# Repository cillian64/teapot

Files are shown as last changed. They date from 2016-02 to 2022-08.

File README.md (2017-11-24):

# TEApot
TEApot: Tiny Environment Analyser.  A
[ukhasnet](https://www.ukhas.net) node with various sensors.
ukhasnet node IDs `TEA0` through `TEAe`.

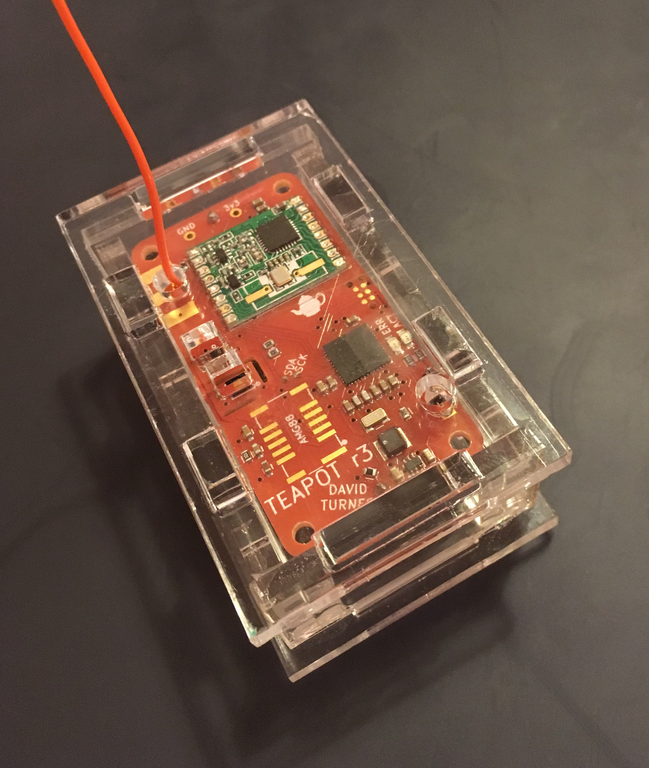
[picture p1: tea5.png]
Photo of TEA5


# Structure
* [board](board/) contains schematics and board layouts for KiCAD EDA 4
* [case](case/) contains plans for laser-cut cases for the nodes
* [firmware](firmware/) contains firmware for the various node flavours
* [software](software/) contains Python3 software for the USB gateway and
  GridEye receiver.

# Nodes
## Hardware
* Microcontroller: STM32F0 and STM32L0
* Power: AA or D alkaline cell with TLV61225 boost switcher
* Assorted sensors:
    * T: Temperature (HTU21d)
    * H: Humidity (HTU21d)
    * P: Pressure (MS5637)
    * S: Light (TEPT4400)
    * X: 8x8 thermopile array (AMG88 Grid-eye)

## Variants
* r2 was the first set manufactured.  Issues with I2C meant sensors did not
  work.  L0 variants are lower power than F0 but do not support USB.  L0
  variants include a RTC crystal.
* r3 was the second set manufactured, omitting USB but including support
  for the Grid-eye sensor and fixing I2C issues.  All boards include an RTC
  crystal.

Node | Board | Sensors | Status
---- | ----- | ------- | ------
TEA0 | r2 F0 |         | USB Gateway, working
TEA1 | r2 L0 |         | Repeater (needs firmware)
TEA2 | r2 L0 |         | Repeater (needs firmware)
TEA3 | r2 L0 |         | Repeater (needs antenna and firmware)
TEA4 | r2 L0 |         | Repeater (needs antenna and firmware)
TEA5 | r3    | THPS    | Working
TEA6 | r3    | THPS    | Working
TEA7 | r3    | THPS    | Working
TEA8 | r3    | THPS    | Working
TEA9 | r3    | THPS    | Working
TEAa | r3    | THPSX   | Grid-eye has checkerboard problem, otherwise ok
TEAb | r3    | THPSX   | Working
TEAc | r3    | THPSX   | Working
TEAd | r3    | THPSX   | Working
TEAe | r3    | THPSX   | Working

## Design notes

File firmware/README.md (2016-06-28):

# Firmware
* `r2` is the first firmware revision written in libopencm3 for the original
  STM32L052K6T6 teapot boards, marked r2.
* `r2_5` is the firmware for the original teapot boards (r2 PCB) with an
  STM32F042K6T7 retrofitted.
* `r3` is the firmware for the new r3 PCBs with an STM32F051C8U7, no USB, and
  the Panasonic Grid-eye AMG88 thermopile array.

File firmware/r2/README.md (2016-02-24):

# Toolchain
This firmware uses the
[gcc-arm-embedded](https://launchpad.net/gcc-arm-embedded) toolchain
recommended by libopencm3.  It can be installed on recent Ubuntu:

`sudo add-apt-repository ppa:team-gcc-arm-embedded/ppa`

`sudo apt-get update`

`sudo apt-get install gcc-arm-embedded`

# Submodules
Check out the correct version of libopencm3:

`git submodule update --init`

# Building, flashing, and debugging
Before doing anything else, build libopencm3:

`cd libopencm3`

`make`

`cd ..`

Then build and flash the firmware:

`make`

`make flash`

To debug:

`make debug`

# Sources
* `teapot.c` contains the start point, `main()`.
* `teapot_pins.h` contains pin assignments on the board, while `teapot_pins.h`
  contains the setup function which assigns pin modes.

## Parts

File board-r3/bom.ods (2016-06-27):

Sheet: BOM
Refs | Onecall part | Order q | Quantity/board | Quantity tot | Cost ea | Board cost | Order cost | N boards | Value | Footprint
D4 | 2290331 | 10 | 1 | 10 | £0.05 | £0.05 | £0.48 | 10 | GREEN | LED_0805
R101 | 9330798 | 10 | 1 | 10 | £0.00 | £0.00 | £0.01 | 10 | 20R | R_0603
C10 C101 C11 C13 C14 C15 C17 C7 | 432210 | 80 | 8 | 80 | £0.02 | £0.12 | £1.20 | 10 | 100n | C_0603
D5 | 2099242 | 10 | 1 | 10 | £0.05 | £0.05 | £0.53 | 10 | YELLOW | LED_0805
P1 | 1702629 | 5 | 1 | 5 | £0.75 | £0.75 | £3.73 | 10 | BATT | AA_holder
IC101 | 2469557 | 10 | 1 | 10 | £1.16 | £1.16 | £11.64 | 10 | STM32F0xxCxUx | QFN-48-EP-ST
C8 C9 | 1759055 | 20 | 2 | 20 | £0.01 | £0.02 | £0.19 | 10 | 15p | C_0603
R5 R6 | 9233385 | 20 | 2 | 20 | £0.01 | £0.01 | £0.10 | 10 | 1k | R_0603
L1 | 2470318 | 10 | 1 | 10 | £0.20 | £0.20 | £1.96 | 10 | 4u7 | Inductor_1212
C103 | 2211176 | 15 | 1 | 10 | £0.14 | £0.14 | £2.13 | 10 | 1.5uF | C_0603
C1 C104 C16 C3 C6 | 2494230 | 50 | 5 | 50 | £0.06 | £0.31 | £3.07 | 10 | 10u | C_0603
U2 | 2492362 | 10 | 1 | 10 | £0.65 | £0.65 | £6.49 | 10 | TLV61225 | SC-70
R1 R3 R4 R7 | 2447230 | 40 | 4 | 40 | £0.00 | £0.01 | £0.09 | 10 | 10k | R_0603
Q1 | SC12389 | 10 | 1 | 10 | £0.25 | £0.25 | £2.46 | 10 | TEPT4400 | LED-3MM
C102 C12 | 2496916 | 20 | 2 | 20 | £0.01 | £0.02 | £0.19 | 10 | 1u | C_0603
U4 | RF00489 | 10 | 1 | 10 | £6.29 | £6.29 | £62.90 | 10 | RFM69W | RFM69
Y1 | 2101347 | 10 | 1 | 10 | £0.34 | £0.34 | £3.43 | 10 | 32.768k | XTAL_1206
D1 D3 | 2368174 | 20 | 2 | 20 | £0.15 | £0.30 | £3.03 | 10 | TVS_small | R_0603
P1 | BT03723 | 5 | 1 | 5 | £0.72 | £0.72 | £3.60 | 5 | BATT | D_holder
OPTIONAL: HTU21D
U6 | 2393536 | 10 | 1 | 10 | £2.52 | £2.52 | £25.17 | 10 | HTU21D | HTU21D
OPTIONAL: MS5637
U7 | 2362663 | 10 | 1 | 10 | £1.51 | £1.51 | £15.09 | 10 | MS5637 | MS563702
OPTIONAL: AMG88
U101 | 2481446 | 5 | 1 | 5 | £23.87 | £23.87 | £119.35 | 5 | AMG88 | AMG88
Total cost per basic board |  |  |  |  |  | £10.66
Total cost per HTU21D/MS5637 board |  |  |  |  |  | £14.69
Total cost per AMG88 board |  |  |  |  |  | £34.53
Total cost per all-in board |  |  |  |  |  | £38.56
Total order cost |  |  |  |  |  | £263.23
Total order cost per board |  |  |  |  |  | £26.32

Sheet: QuickPaste
Onecall part | Order q | Value
2290331 | 10 | GREEN
9330798 | 10 | 20R
432210 | 80 | 100n
2099242 | 10 | YELLOW
1702629 | 5 | BATT
2469557 | 10 | STM32F0xxCxUx
1759055 | 20 | 15p
9233385 | 20 | 1k
2470318 | 10 | 4u7
2211176 | 15 | 1.5uF
2494230 | 50 | 10u
2492362 | 10 | TLV61225
2447230 | 40 | 10k
SC12389 | 10 | TEPT4400
2496916 | 20 | 1u
RF00489 | 10 | RFM69W
2101347 | 10 | 32.768k
2368174 | 20 | TVS_small
BT03723 | 5 | BATT
2393536 | 10 | HTU21D
2362663 | 10 | MS5637
2481446 | 5 | AMG88

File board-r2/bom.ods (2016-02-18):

Refs | Onecall part | Order q | Quantity/board | Quantity tot | Cost ea | Board cost | Order cost | Value | Footprint | Comment
D4 | 2290331 | 7 | 1 | 5 | £0.06 | £0.06 | £0.39 | GREEN | LED_0805
U1 | 1470478 | 1 | 1 | 5 | £0.17 | £0.17 | £0.17 | TPS79333DBVR | SOT-23-5 | Optional – USB
C10,C11,C13,C14,C15,C17,C2,C7 | 432210 | 50 | 8 | 40 | £0.01 | £0.04 | £0.26 | 100n | C_0603 | 1 Optional – USB, 1 optional – pressure
P1 | 1702629 | 4 | 1 | 5 | £0.75 | £0.75 | £2.98 | BATT | AA_holder
C8,C9 | 1759055 | 20 | 2 | 10 | £0.01 | £0.01 | £0.13 | 15p | C_0603
R2,R5,R6 | 9233385 | 20 | 3 | 15 | £0.00 | £0.01 | £0.07 | 1k | R_0603
U5 | 2488333 | 5 | 1 | 5 | £2.10 | £2.10 | £10.50 | STM32L052K6T6 | LQFP32_ST
U7 | 2362663 | 1 | 1 | 5 | £1.51 | £1.51 | £1.51 | MS5637 | MS563702 | Optional – Pressure
L1 | 2470318 | 5 | 1 | 5 | £0.18 | £0.18 | £0.91 | 4u7 | Inductor_1212
C1,C16,C3,C5,C6 | 2494230 | 30 | 5 | 25 | £0.04 | £0.21 | £1.24 | 10u | C_0603
D2 | 2099241 | 10 | 1 | 5 | £0.07 | £0.07 | £0.65 | RED | LED_0805
U2 | 2492362 | 4 | 1 | 5 | £0.63 | £0.63 | £2.53 | TLV61225 | SC-70
U6 | 2393536 | 5 | 1 | 5 | £2.52 | £2.52 | £12.59 | HTU21D | HTU21D
P2 | 1342651 | 1 | 1 | 5 | £2.87 | £2.87 | £2.87 | SMA | SMA-142-0701-801
J1 | 1568023 | 1 | 1 | 5 | £0.26 | £0.26 | £0.26 | MICROUSB | MICROUSB_MOLEX_47589-0001
R1,R3,R4,R7 | 2447230 | 30 | 4 | 20 | £0.00 | £0.02 | £0.12 | 10k | R_0603
Q1 | SC12389 | 5 | 1 | 5 | £0.25 | £0.25 | £1.23 | TEPT4400 | LED-3MM
C12 | 2496916 | 10 | 1 | 5 | £0.01 | £0.01 | £0.08 | 1u | C_0603
D5 | 2099242 | 10 | 1 | 5 | £0.06 | £0.06 | £0.64 | YELLOW | LED_0805
Y1 | 2101347 | 5 | 1 | 5 | £0.33 | £0.33 | £1.64 | 32.768k | XTAL_1206
D1,D3 | 2368174 | 10 | 2 | 10 | £0.15 | £0.30 | £1.52 | TVS_small | R_0603
U4 | RF00489 | 5 | 1 | 5 | £4.00 | £4.00 | £20.00 | RFM69HW-868S2 | RFM69W
TOTAL BOARD COST minus PCBs and tooling |  |  |  |  |  | £16.35
TOTAL ONECALL ORDER COST |  |  |  |  |  |  | £62.28
 |  |  |  | Total onecall per board |  |  | £12.46
 |  |  |  |  | £6.79

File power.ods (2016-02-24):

Component | Boost loss | stm32l052 | rfm69w | htu21d | ms5637 | tept4400 | total |  | All in uA referred to 3v3
Boost Quiescent | 20 | - | - | - | - | - | -
STM32 run | - | 3000 | - | - | - | - | -
STM32 sleep | - | 670 | - | - | - | - | -
STM32 LP run | - | 40 | - | - | - | - | -
STM32 LP sleep | - | 20 | - | - | - | - | -
STM32 Stop +RTC | - | 1 | - | - | - | - | -
RFM69W Sleep | - | - | 0.1 | - | - | - | -
RFM69W Idle +RC | - | - | 1.2 | - | - | - | -
RFM69W Standby +XTAL | - | - | 1250 | - | - | - | -
RFM69W RX | - | - | 16000 | - | - | - | -
RFM69W TX 0dBm | - | - | 20000 | - | - | - | -
RFM69W TX +13dBm | - | - | 45000 | - | - | - | -
HTU21D sleep | - | - | - | 0.02 | - | - | -
HTU21D measure | - | - | - | 450 | - | - | -
MS5637 standby | - | - | - | - | 0.01 | - | -
MS5637 measure | - | - | - | - | 20 | - | -
TEPT4400 dark | - | - | - | - | - | 5 | -
TEPT4400 hallway | - | - | - | - | - | 200 | -
TEPT4400 office | - | - | - | - | - | 800 | -
TEPT4400 overcast | - | - | - | - | - | 2000 | -
State |  |  |  |  |  |  |  | Time/ms
Sleep | 20.00 | 1.00 | 1.20 | 0.02 | 0.01 | 0.00 | 22.23 | 60000 | every minute
Measurement | 20.00 | 3000.00 | 0.10 | 450.00 | 20.00 | 800.00 | 4290.10 | 6
TX | 20.00 | 3000.00 | 45000.00 | 0.02 | 0.01 | 0.00 | 48020.03 | 33
RX (gateway) | 20.00 | 3000.00 | 16000.00 | 0.02 | 0.01 | 0.00 | 19020.03 | 0
TOTAL (time-average) | 20.00 | 2.95 | 25.93 | 0.06 | 0.01 | 0.08 | 49.04 | 60039
 |  |  |  |  |  |  | Ave I / uA: | 49.04
 |  |  |  |  |  |  | AA life | 22246.13 | hours
 |  |  |  |  |  |  | AA life | 926.92 | days
 |  |  |  |  |  |  | AA life | 2.54 | years

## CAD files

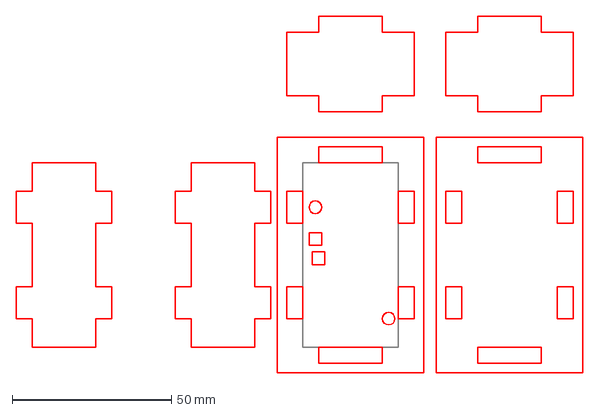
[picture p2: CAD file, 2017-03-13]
case/r3.dxf
178.0 x 112.0 mm

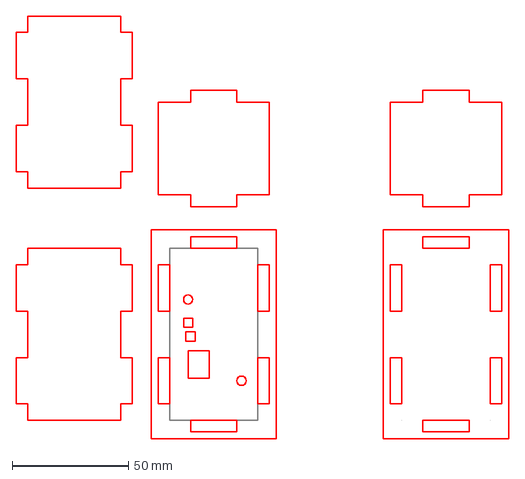
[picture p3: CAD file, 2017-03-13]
case/r3-grideye.dxf
212.0 x 182.0 mm

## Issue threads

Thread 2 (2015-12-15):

Check power consumption against boost regulator limit

cillian64, 2015-12-15:

cillian64, 2015-12-22:
stm32 at full whack plus transmit at +13dBm draws 48mA, which the booster can supply above 1V in.  Below that we might have issues.

Closed 2015-12-22.

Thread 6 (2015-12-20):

Add USB connector -- get fixed supervide schematic off adam

cillian64, 2015-12-20:

Closed 2015-12-21.

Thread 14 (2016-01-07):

mounting hole clearance

cillian64, 2016-01-07:

Closed 2016-01-07.

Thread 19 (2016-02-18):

Case holes failed

cillian64, 2016-02-18:
LED and antenna holes are too small and get merged closed, on quick print at least.

Closed 2016-02-19.

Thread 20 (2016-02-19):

Upper ledge for screw fixing is weird/unnecessary

cillian64, 2016-02-19:

Closed 2016-02-19.

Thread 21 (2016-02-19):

CS hole on lid, add insert to give clearance

cillian64, 2016-02-19:

Closed 2016-02-19.

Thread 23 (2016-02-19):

Walls are wibbly

cillian64, 2016-02-19:
Add ribs as appropriate

cillian64, 2017-11-24:
Laser-cut cases are no longer wibbly.

Closed 2017-11-24.

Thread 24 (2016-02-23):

Board is an excessively tight fit in case

cillian64, 2016-02-23:
Make everything bigger?
More headroom to include rfm69w?
Slot for TEPT4400
Or just rethink design from scratch?

cillian64, 2017-11-24:
Laser-cut cases are a perfect fit

Closed 2017-11-24.

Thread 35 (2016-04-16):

HTU21d footprint/pinout is wrong.

cillian64, 2016-04-16:

Closed 2016-06-17.

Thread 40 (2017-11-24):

Humidity sensor has some dropouts

cillian64, 2017-11-24:
It seems to depend on humidity level.  The latest firmware may fix this issue, I need to reflash all the nodes to find out.

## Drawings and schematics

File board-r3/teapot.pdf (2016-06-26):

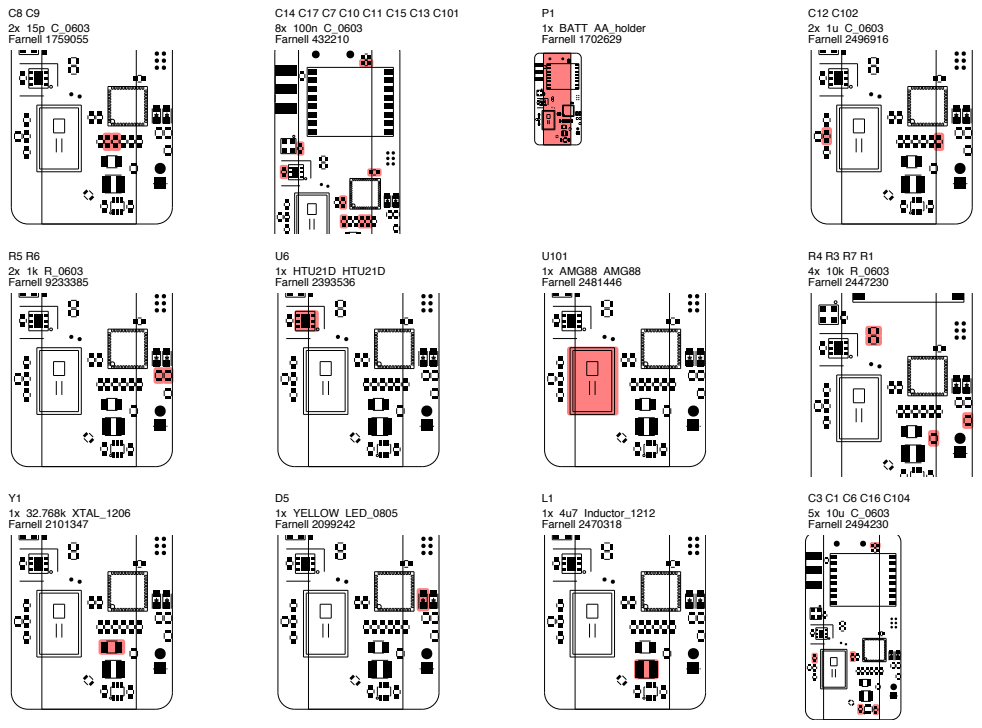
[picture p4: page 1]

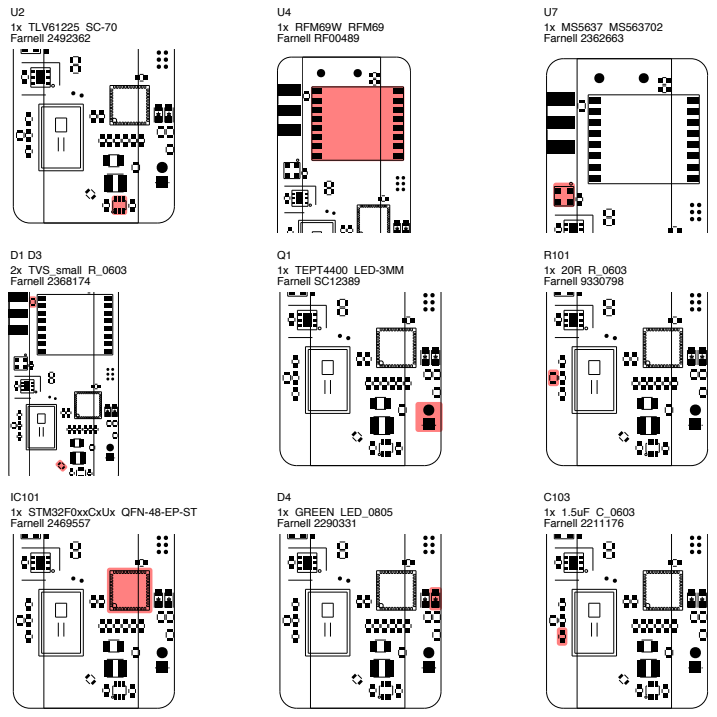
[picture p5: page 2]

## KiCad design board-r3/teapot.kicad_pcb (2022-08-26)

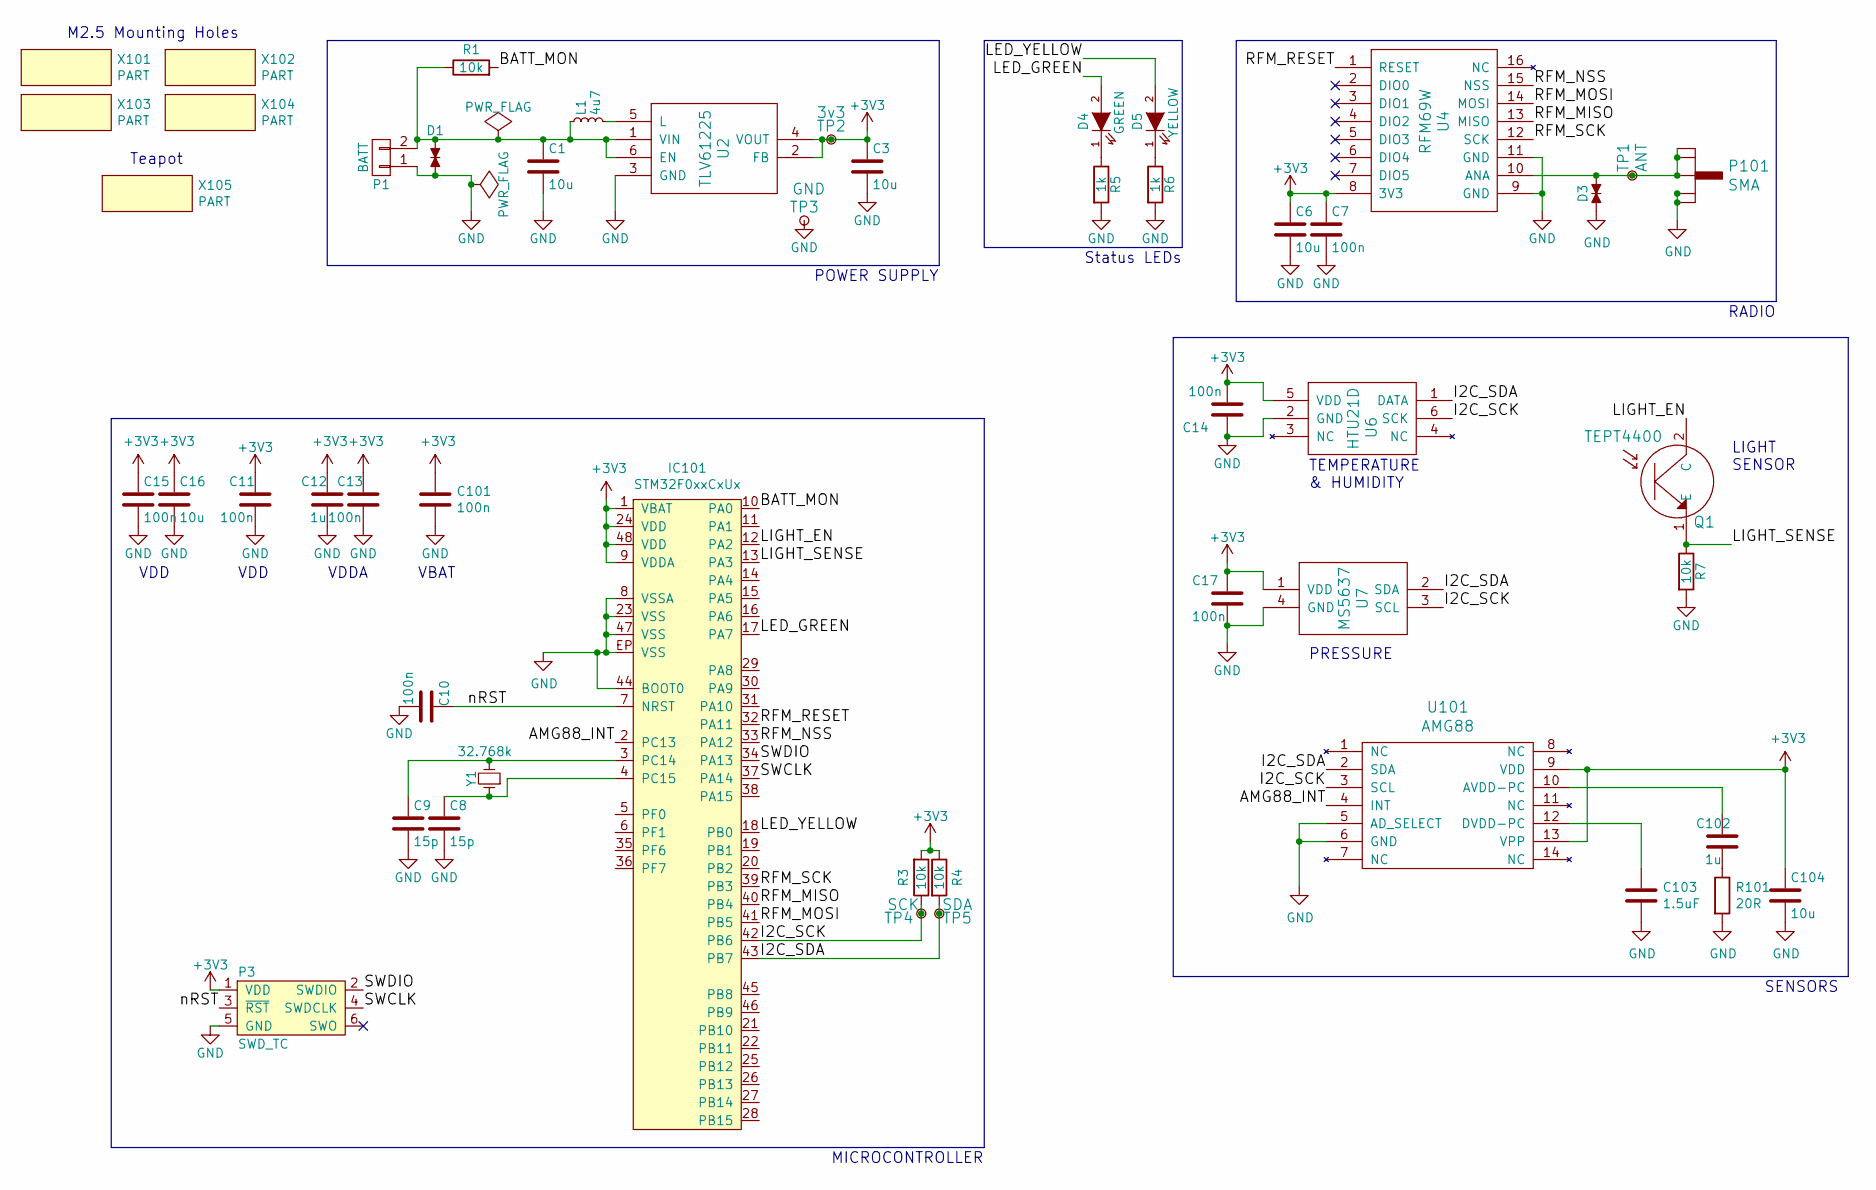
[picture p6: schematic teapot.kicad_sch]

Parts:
C1, C3, C6, C16, C104: 10u; C_0603; Farnell 2494230
C7, C10, C11, C13, C14, C15, C17, C101: 100n; C_0603; Farnell 432210
C8, C9: 15p; C_0603; Farnell 1759055
C12, C102: 1u; C_0603; Farnell 2496916
C103: 1.5uF; C_0603; Farnell 2211176
D1, D3: TVS_small; R_0603; Farnell 2368174
D4: GREEN; LED_0805; Farnell 2290331
D5: YELLOW; LED_0805; Farnell 2099242
IC101: STM32F0xxCxUx; QFN-48-EP-ST; Farnell 2469557
L1: 4u7; Inductor_1212; Farnell 2470318
P1: BATT; AA_holder; Farnell 1702629
P3: SWD_TC; TC2030-NL
P101: SMA; SMA-142-0701-801
Q1: TEPT4400; LED-3MM; Farnell SC12389
R1, R3, R4, R7: 10k; R_0603; Farnell 2447230
R5, R6: 1k; R_0603; Farnell 9233385
R101: 20R; R_0603; Farnell 9330798
TP1: ANT; Test_point
TP2: 3v3; Test_point
TP3: GND; Test_point
TP4: SCK; Test_point_mini
TP5: SDA; Test_point_mini
U2: TLV61225; SC-70; Farnell 2492362
U4: RFM69W; RFM69; Farnell RF00489
U6: HTU21D; Farnell 2393536
U7: MS5637; MS563702; Farnell 2362663
U101: AMG88; Farnell 2481446
X101, X102, X103, X104: PART; MountingHole_2.7mm_M2.5
X105: PART; teapot
Y1: 32.768k; XTAL_1206; Farnell 2101347

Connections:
+3V3: C3.1, C6.1, C7.1, C11.1, C12.1, C13.1, C14.2, C15.1, C16.1, C17.1, C101.1, C104.1, IC101.1 (VBAT), IC101.9 (VDDA), IC101.24 (VDD), IC101.48 (VDD), P3.1 (VDD), R3.2, R4.1, TP2.1, U2.2 (FB), U2.4 (VOUT), U4.8 (3V3), U6.5 (VDD), U7.1 (VDD), U101.9 (VDD), U101.13 (VPP)
/AMG88_INT: IC101.2 (PC13), U101.4 (INT)
/BATT_MON: IC101.10 (PA0), R1.2
/I2C_SCK: IC101.42 (PB6), R3.1, TP4.1, U6.6 (SCK), U7.3 (SCL), U101.3 (SCL)
/I2C_SDA: IC101.43 (PB7), R4.2, TP5.1, U6.1 (DATA), U7.2 (SDA), U101.2 (SDA)
/LED_GREEN: D4.2 (A), IC101.17 (PA7)
/LED_YELLOW: D5.2 (A), IC101.18 (PB0)
/LIGHT_EN: IC101.12 (PA2), Q1.2 (C)
/LIGHT_SENSE: IC101.13 (PA3), Q1.1 (E), R7.1
/RFM_MISO: IC101.40 (PB4), U4.13 (MISO)
/RFM_MOSI: IC101.41 (PB5), U4.14 (MOSI)
/RFM_NSS: IC101.33 (PA12), U4.15 (NSS)
/RFM_RESET: IC101.32 (PA11), U4.1 (RESET)
/RFM_SCK: IC101.39 (PB3), U4.12 (SCK)
/SWCLK: IC101.37 (PA14), P3.4 (SWDCLK)
/SWDIO: IC101.34 (PA13), P3.2 (SWDIO)
/nRST: C10.1, IC101.7 (NRST), P3.3 (~RST)
unnamed: C1.1, D1.1, L1.1, P1.2, R1.1, U2.1 (VIN), U2.6 (EN)
unnamed: C8.1, IC101.4 (PC15), Y1.1
unnamed: C9.1, IC101.3 (PC14), Y1.2
unnamed: C102.1, U101.10 (AVDD-PC)
unnamed: C102.2, R101.1
unnamed: C103.1, U101.12 (DVDD-PC)
unnamed: D4.1 (K), R5.1
unnamed: D5.1 (K), R6.1
unnamed: L1.2, U2.5 (L)

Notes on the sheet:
POWER SUPPLY
VBAT
SENSORS
PRESSURE
MICROCONTROLLER
M2.5 Mounting Holes
VDD
Teapot
LIGHT SENSOR
Status LEDs
TEMPERATURE & HUMIDITY
VDDA
RADIO

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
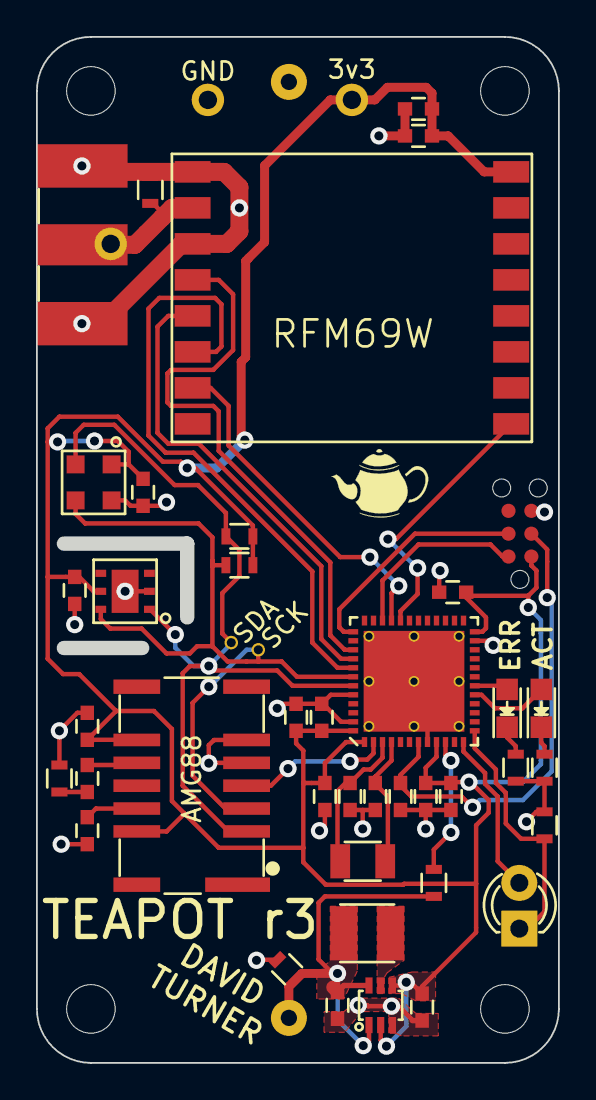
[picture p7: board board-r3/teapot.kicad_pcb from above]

Board: 2 copper layers, 29.0 x 57.0 mm, 51 parts (0 on the bottom side), 28 nets.

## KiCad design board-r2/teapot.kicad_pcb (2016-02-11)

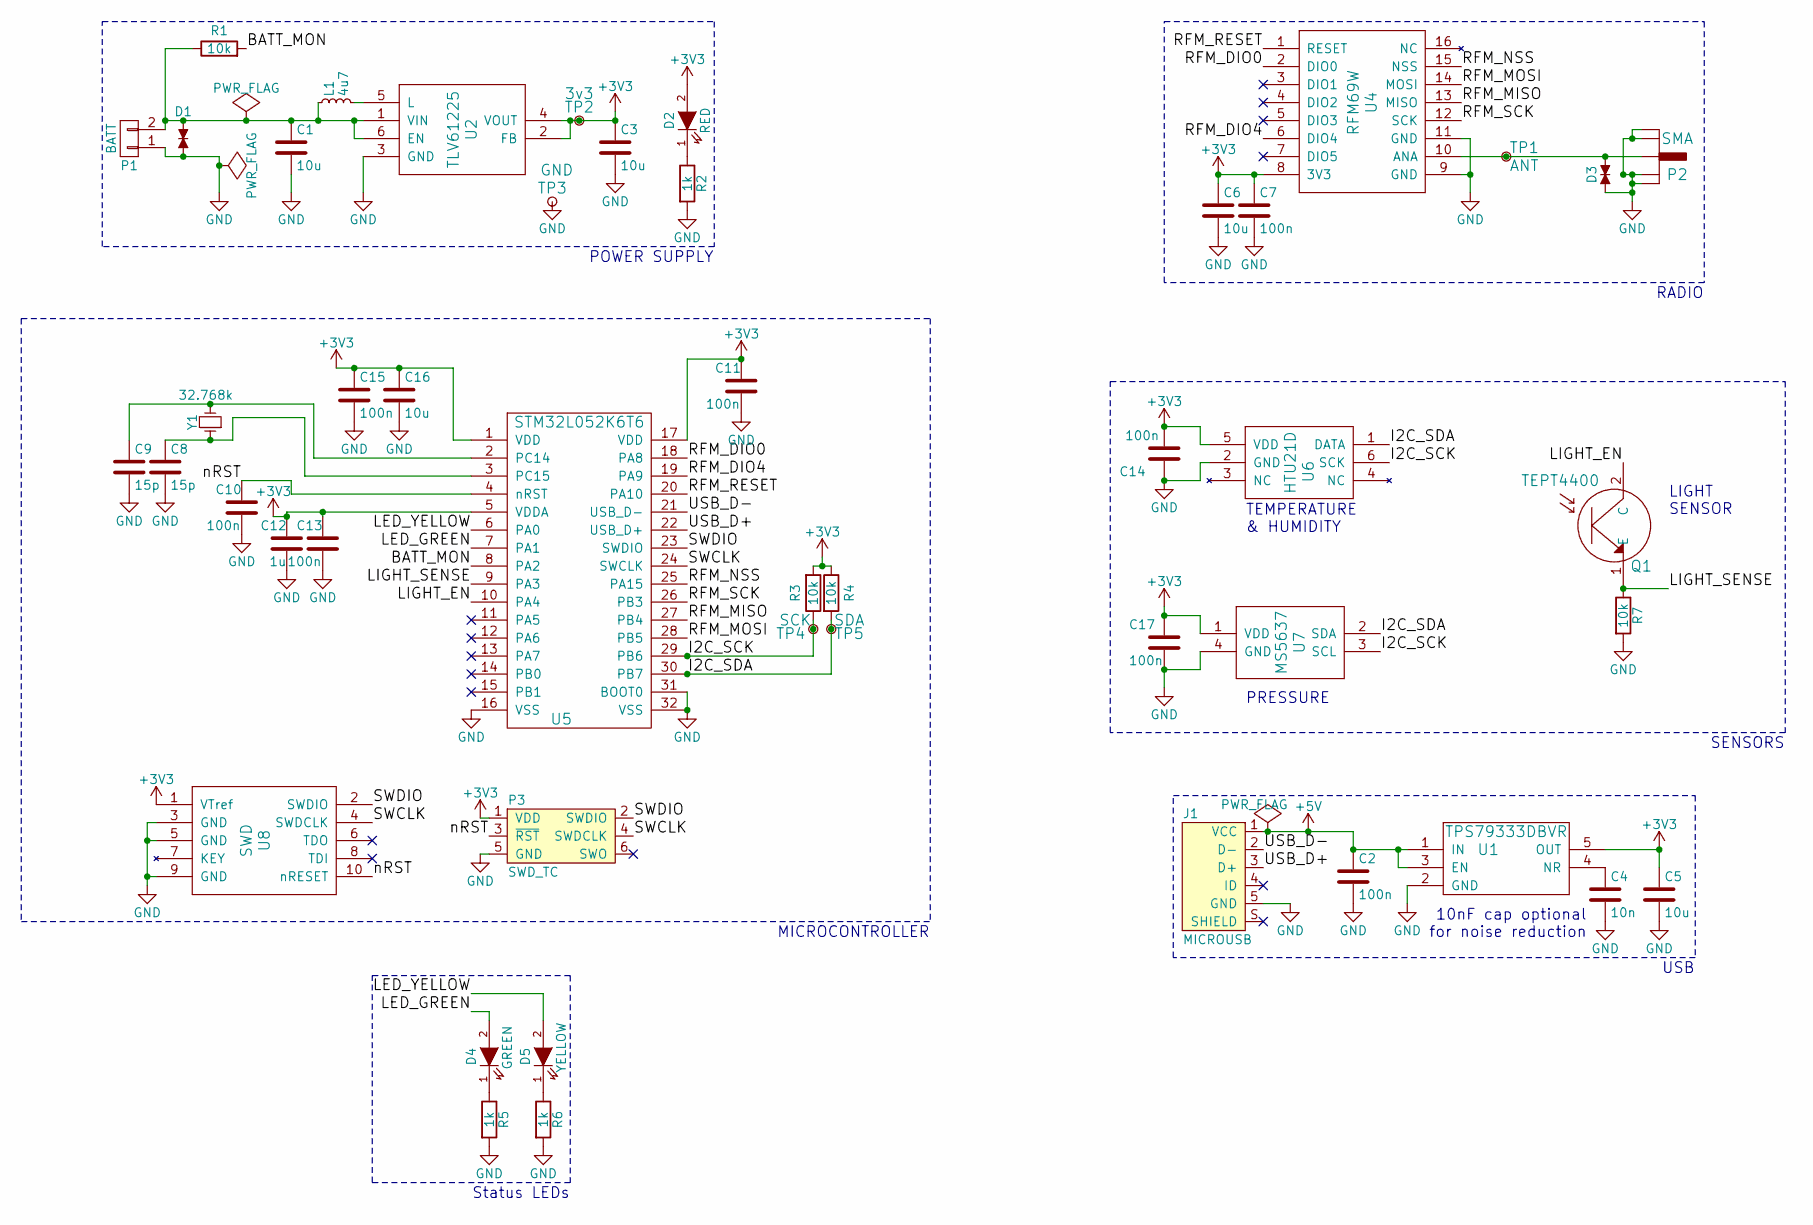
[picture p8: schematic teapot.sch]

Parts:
C1, C3, C5, C6, C16: 10u; C_0603; Farnell 2494230
C2, C7, C10, C11, C13, C14, C15, C17: 100n; C_0603; Farnell 432210
C4: 10n; C_0603
C8, C9: 15p; C_0603; Farnell 1759055
C12: 1u; C_0603; Farnell 2496916
D1, D3: TVS_small; R_0603; Farnell 2368174
D2: RED; LED_0805; Farnell 2099241
D4: GREEN; LED_0805; Farnell 2290331
D5: YELLOW; LED_0805; Farnell 2099242
J1: MICROUSB; MICROUSB_MOLEX_47589-0001; Farnell 1568023
L1: 4u7; Inductor_1212; Farnell 2470318
P1: BATT; AA_holder; Farnell 1702629
P2: SMA; SMA-142-0701-801; Farnell 1342651
P3: SWD_TC; TC2030-NL
Q1: TEPT4400; LED-3MM; Farnell SC12389
R1, R3, R4, R7: 10k; R_0603; Farnell 2447230
R2, R5, R6: 1k; R_0603; Farnell 9233385
TP1: ANT; Test_point
TP2: 3v3; Test_point
TP3: GND; Test_point
TP4: SCK; Test_point_mini
TP5: SDA; Test_point_mini
U1: TPS79333DBVR; SOT-23-5; Farnell 1470478
U2: TLV61225; SC-70; Farnell 2492362
U4: RFM69W; RFM69
U5: STM32L052K6T6; LQFP32_ST; Farnell 2488333
U6: HTU21D; Farnell 2393536
U7: MS5637; MS563702; Farnell 2362663
U8: SWD
Y1: 32.768k; XTAL_1206; Farnell 2101347

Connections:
+3V3: C3.1, C5.1, C6.1, C7.1, C11.1, C12.1, C13.1, C14.2, C15.1, C16.1, C17.1, D2.2 (A), P3.1 (VDD), R3.2, R4.1, TP2.1, U1.5 (OUT), U2.2 (FB), U2.4 (VOUT), U4.8 (3V3), U5.1 (VDD), U5.5 (VDDA), U5.17 (VDD), U6.5 (VDD), U7.1 (VDD), U8.1 (VTref)
+5V: C2.1, J1.1 (VCC), U1.1 (IN), U1.3 (EN)
/BATT_MON: R1.2, U5.8 (PA2)
/I2C_SCK: R3.1, TP4.1, U5.29 (PB6), U6.6 (SCK), U7.3 (SCL)
/I2C_SDA: R4.2, TP5.1, U5.30 (PB7), U6.1 (DATA), U7.2 (SDA)
/LED_GREEN: D4.2 (A), U5.7 (PA1)
/LED_YELLOW: D5.2 (A), U5.6 (PA0)
/LIGHT_EN: Q1.2 (C), U5.10 (PA4)
/LIGHT_SENSE: Q1.1 (E), R7.1, U5.9 (PA3)
/RFM_DIO0: U4.2 (DIO0), U5.18 (PA8)
/RFM_DIO4: U4.6 (DIO4), U5.19 (PA9)
/RFM_MISO: U4.13 (MISO), U5.27 (PB4)
/RFM_MOSI: U4.14 (MOSI), U5.28 (PB5)
/RFM_NSS: U4.15 (NSS), U5.25 (PA15)
/RFM_RESET: U4.1 (RESET), U5.20 (PA10)
/RFM_SCK: U4.12 (SCK), U5.26 (PB3)
/SWCLK: P3.4 (SWDCLK), U5.24 (SWCLK), U8.4 (SWDCLK)
/SWDIO: P3.2 (SWDIO), U5.23 (SWDIO), U8.2 (SWDIO)
/USB_D+: J1.3 (D+), U5.22 (USB_D+)
/USB_D-: J1.2 (D-), U5.21 (USB_D-)
/nRST: C10.1, P3.3 (~RST), U5.4 (nRST), U8.10 (nRESET)
GND: C1.2, C2.2, C3.2, C4.2, C5.2, C6.2, C7.2, C8.2, C9.2, C10.2, C11.2, C12.2, C13.2, C14.1, C15.2, C16.2, C17.2, D1.2, D3.1, J1.5 (GND), P1.1, P2.2 (GND), P2.3 (GND), P2.4 (GND), P2.5 (GND), P3.5 (GND), R2.2, R5.2, R6.2, R7.2, TP3.1, U1.2 (GND), U2.3 (GND), U4.9 (GND), U4.11 (GND), U5.16 (VSS), U5.31 (BOOT0), U5.32 (VSS), U6.2 (GND), U7.4 (GND), U8.3 (GND), U8.5 (GND), U8.9 (GND)
unnamed: C1.1, D1.1, L1.1, P1.2, R1.1, U2.1 (VIN), U2.6 (EN)
unnamed: C4.1, U1.4 (NR)
unnamed: C8.1, U5.3 (PC15), Y1.1
unnamed: C9.1, U5.2 (PC14), Y1.2
unnamed: D2.1 (K), R2.1
unnamed: D3.2, P2.1 (RF), TP1.1, U4.10 (ANA)
unnamed: D4.1 (K), R5.1
unnamed: D5.1 (K), R6.1
unnamed: L1.2, U2.5 (L)

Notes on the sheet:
PRESSURE
TEMPERATURE & HUMIDITY
POWER SUPPLY
LIGHT SENSOR
RADIO
MICROCONTROLLER
USB
10nF cap optional for noise reduction
Status LEDs
SENSORS

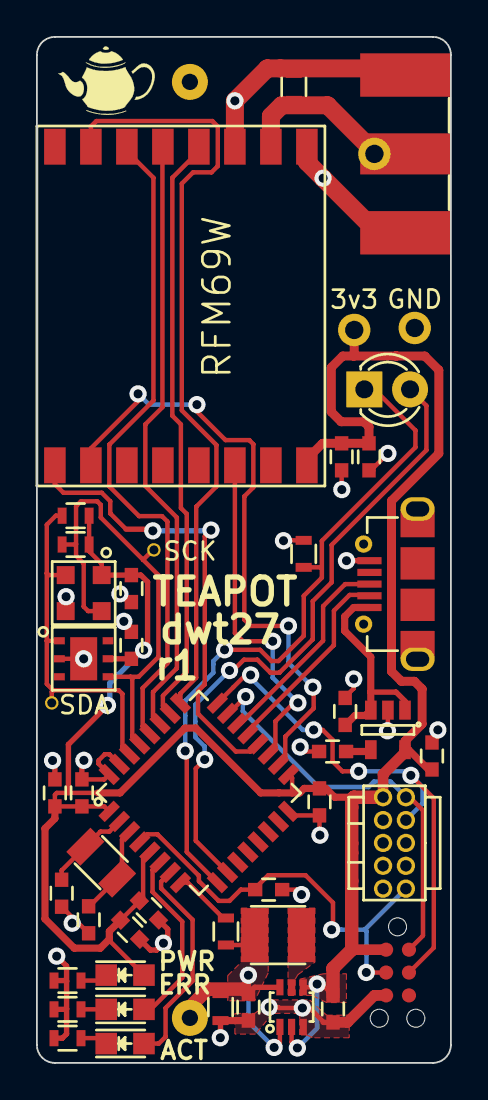
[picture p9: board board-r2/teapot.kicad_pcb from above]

Board: 2 copper layers, 23.0 x 57.0 mm, 48 parts (0 on the bottom side), 31 nets.

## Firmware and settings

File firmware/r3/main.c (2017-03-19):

#include <string.h>

#include "ch.h"
#include "hal.h"
#include "ch_test.h"

#include "analog.h"
#include "rfm69.h"
#include "ukhasnet.h"
#include "grid-eye.h"
#include "sensors.h"
#include "base64.h"
#include "flash.h"
#include "lowpower.h"

#ifdef SEMIHOSTING
#include <stdio.h>
#endif

static const I2CConfig i2cconfig = {
//    0xffff,
    1<<31 | 1<<30 | 1<<29 | 1<<28, // TIMINGR
    0,      // CR1
    0,      // CR2
};

#ifdef SEMIHOSTING
void initialise_monitor_handles(void);

/* Puts with no newline */
void puts_non(char *str);
void puts_non(char *str)
{
    for(uint32_t i=0; i<strlen(str); i++)
        putchar(str[i]);
}
#endif

int main(void)
{
    halInit();
    chSysInit();

    flash_config_t *config = chHeapAlloc(NULL, sizeof(flash_config_t));
    // Uncomment below to write config to flash memory.
    // strcpy(config->nodeid, "TEA8");
    // config->ttl = 3;
    // config->interval = 60;
    // config->has_battery = true;
    // config->has_temperature = true;
    // config->has_humidity = true;
    // config->has_pressure = true;
    // config->has_light = false;
    // config->has_grideye = false;
    // flash_write_config(config);
    flash_read_config(config);

    char seq;
    if(lowpower_woken_from_standby())
        seq = lowpower_get_sequence();
    else
        seq = 'a';

    analog_init();
    ukhasnet_radio_init();

    // On first boot wait for things to warm up to avoid weird i2c issues
    if(seq == 'a')
        chThdSleepMilliseconds(1000);

    palClearLine(LINE_LED_YELLOW);
    palClearLine(LINE_LED_GREEN);

#ifdef SEMIHOSTING
    initialise_monitor_handles();
    setbuf(stdout, NULL);
    puts("Hello, world.");
#endif

    spiStop(&SPID1);
    i2cStart(&I2CD1, &i2cconfig);
    pressure_init();
    i2cStop(&I2CD1);

    // Buffers
    uint8_t *packetbuf = chHeapAlloc(NULL, 64*sizeof(uint8_t));

    // GRIDEYE stuff.  Allocate whether or not we actually have a grideye
    uint16_t *pixels = chHeapAlloc(NULL, 64*sizeof(uint16_t));
    uint8_t *packed_pixels = chHeapAlloc(NULL, 36*sizeof(uint8_t));
    char *b64_pixels = chHeapAlloc(NULL, 49*sizeof(char));
    uint16_t grid_average;

    uint8_t packet_len;
    uint32_t pressure;
    uint8_t battery;
    uint16_t light;
    uint16_t temperature;
    uint8_t humidity;

    while(true)
    {
        // Begin activity
        palSetLine(LINE_LED_GREEN);

        // Read analog sensors.
        analog_read(&battery, &light);
        // Read I2C sensors. Swap from SPI to I2C
        spiStop(&SPID1);
        i2cStart(&I2CD1, &i2cconfig);
        temperature = convert_temperature(get_temperature());
        humidity = convert_humidity(get_humidity());
        pressure = get_pressure();
        if(config->has_grideye)
            grideye_get(pixels);
        i2cStop(&I2CD1);
        ukhasnet_radio_init();

       // Send sensor packet:
       packet_len = makepacket(packetbuf, 64, &seq, config->nodeid,
                               config->ttl,
                               config->has_battery, battery,
                               config->has_temperature, temperature,
                               config->has_humidity, humidity,
                               config->has_pressure, pressure,
                               config->has_light, light,
                               "");
       rfm69_transmit(packetbuf, packet_len);

        // For Grid-eye send another packet with pixels:
        if(config->has_grideye)
        {
            chThdSleepMilliseconds(100);
            grid_average = grideye_pack(pixels, packed_pixels);
            packed_pixels[32] = grid_average >> 8;
            packed_pixels[33] = grid_average & 0xff;
            packed_pixels[34] = pixels[32] >> 8;
            packed_pixels[35] = pixels[32] & 0xff;
            b64encode(packed_pixels, 36, b64_pixels);
            b64_pixels[48] = '\0';

            packet_len = makepacket(packetbuf, 64, &seq,
                                    config->nodeid,
                                    0, // Disable grideye repeating
                                    false, 0, false, 0, false, 0,
                                    false, 0, false, 0,
                                    b64_pixels);
            rfm69_transmit(packetbuf, packet_len);
        }

        // End activity and clean up for standby mode
        palClearLine(LINE_LED_GREEN);
        rfm69_setmode(RFM69_OPMODE_SLEEP);
        i2cStop(&I2CD1);
        spiStop(&SPID1);
        adcStop(&ADCD1);

        lowpower_set_sequence(seq);
        lowpower_set_wakeup_timer(config->interval);
        lowpower_do_standby();
    }
}

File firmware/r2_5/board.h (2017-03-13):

/*
    ChibiOS - Copyright (C) 2006..2016 Giovanni Di Sirio

    Licensed under the Apache License, Version 2.0 (the "License");
    you may not use this file except in compliance with the License.
    You may obtain a copy of the License at

        http://www.apache.org/licenses/LICENSE-2.0

    Unless required by applicable law or agreed to in writing, software
    distributed under the License is distributed on an "AS IS" BASIS,
    WITHOUT WARRANTIES OR CONDITIONS OF ANY KIND, either express or implied.
    See the License for the specific language governing permissions and
    limitations under the License.
*/

#ifndef BOARD_H
#define BOARD_H

/*
 * Board identifier.
 */
#define BOARD_NAME                  "Teapot r2.5"

/*
 * Board oscillators-related settings.
 * NOTE: HSE not fitted.
 * NOTE: LSE fitted but not connected, because pins not available
 */
#if !defined(STM32_LSECLK)
#define STM32_LSECLK                0U
#endif

#define STM32_LSEDRV                (3U << 3U)

#if !defined(STM32_HSECLK)
#define STM32_HSECLK                0U
#endif

/*
 * MCU type as defined in the ST header.
 */
#define STM32F042x6

/*
 * IO pins assignments.
 */
#define GPIOA_LED_YELLOW            0U
#define GPIOA_LED_GREEN             1U
#define GPIOA_BATT_MON              2U
#define GPIOA_LIGHT_SENSE           3U
#define GPIOA_LIGHT_EN              4U
#define GPIOA_PIN5                  5U
#define GPIOA_PIN6                  6U
#define GPIOA_PIN7                  7U
#define GPIOA_RFM_DIO0              8U
#define GPIOA_RFM_DIO4              9U
#define GPIOA_RFM_RESET             10U
#define GPIOA_USB_DM                11U
#define GPIOA_USB_DP                12U
#define GPIOA_SWDIO                 13U
#define GPIOA_SWCLK                 14U
#define GPIOA_RFM_NSS               15U

#define GPIOB_PIN0                  0U
#define GPIOB_PIN1                  1U
#define GPIOB_PIN2                  2U
#define GPIOB_RFM_SCK               3U
#define GPIOB_RFM_MISO              4U
#define GPIOB_RFM_MOSI              5U
#define GPIOB_I2C_SCK               6U
#define GPIOB_I2C_SDA               7U
#define GPIOB_PIN8                  8U
#define GPIOB_PIN9                  9U
#define GPIOB_PIN10                 10U
#define GPIOB_PIN11                 11U
#define GPIOB_PIN12                 12U
#define GPIOB_PIN13                 13U
#define GPIOB_PIN14                 14U
#define GPIOB_PIN15                 15U

#define GPIOC_PIN0                  0U
#define GPIOC_PIN1                  1U
#define GPIOC_PIN2                  2U
#define GPIOC_PIN3                  3U
#define GPIOC_PIN4                  4U
#define GPIOC_PIN5                  5U
#define GPIOC_PIN6                  6U
#define GPIOC_PIN7                  7U
#define GPIOC_PIN8                  8U
#define GPIOC_PIN9                  9U
#define GPIOC_PIN10                 10U
#define GPIOC_PIN11                 11U
#define GPIOC_PIN12                 12U
#define GPIOC_PIN13                 13U
#define GPIOC_PIN14                 14U
#define GPIOC_PIN15                 15U

#define GPIOD_PIN0                  0U
#define GPIOD_PIN1                  1U
#define GPIOD_PIN2                  2U
#define GPIOD_PIN3                  3U
#define GPIOD_PIN4                  4U
#define GPIOD_PIN5                  5U
#define GPIOD_PIN6                  6U
#define GPIOD_PIN7                  7U
#define GPIOD_PIN8                  8U
#define GPIOD_PIN9                  9U
#define GPIOD_PIN10                 10U
#define GPIOD_PIN11                 11U
#define GPIOD_PIN12                 12U
#define GPIOD_PIN13                 13U
#define GPIOD_PIN14                 14U
#define GPIOD_PIN15                 15U

#define GPIOE_PIN0                  0U
#define GPIOE_PIN1                  1U
#define GPIOE_PIN2                  2U
#define GPIOE_PIN3                  3U
#define GPIOE_PIN4                  4U
#define GPIOE_PIN5                  5U
#define GPIOE_PIN6                  6U
#define GPIOE_PIN7                  7U
#define GPIOE_PIN8                  8U
#define GPIOE_PIN9                  9U
#define GPIOE_PIN10                 10U
#define GPIOE_PIN11                 11U
#define GPIOE_PIN12                 12U
#define GPIOE_PIN13                 13U
#define GPIOE_PIN14                 14U
#define GPIOE_PIN15                 15U

#define GPIOF_PIN0                  0U
#define GPIOF_PIN1                  1U
#define GPIOF_PIN2                  2U
#define GPIOF_PIN3                  3U
#define GPIOF_PIN4                  4U
#define GPIOF_PIN5                  5U
#define GPIOF_PIN6                  6U
#define GPIOF_PIN7                  7U
#define GPIOF_PIN8                  8U
#define GPIOF_PIN9                  9U
#define GPIOF_PIN10                 10U
#define GPIOF_PIN11                 11U
#define GPIOF_PIN12                 12U
#define GPIOF_PIN13                 13U
#define GPIOF_PIN14                 14U
#define GPIOF_PIN15                 15U
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

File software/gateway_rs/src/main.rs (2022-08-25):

use std::io::BufRead;
use std::io::BufReader;
use std::time::Duration;

mod ukhn_to_influx;

/// Gateway name
const ORIGIN: &str = "TEA0";

/// Open a serial port at the specified path.  Keeps trying (and blocks) until
/// we can successfully open one.
///
/// # Arguments
///
/// * `path` - OS-dependent path to the serial port to open
///
/// # Returns
///
/// * Some sort of serial port (which type depends on the OS).
fn open_serial_port(path: &str) -> Box<dyn serialport::SerialPort> {
    let timeout = Duration::new(1, 0); // one second
    loop {
        let maybe_port = serialport::new(path, 115_200).timeout(timeout).open();
        if let Ok(port) = maybe_port {
            return port;
        }
    }
}

/// Try to upload a packet to InfluxDB.  No action is taken if the upload
/// fails.
///
/// # Arguments
///
/// * `packet` - Trimmed string received from the gateway hardware
fn upload_to_influx(line: &str) {
    let url = "http://localhost:8086/write?db=ukhasnet";

    eprintln!("line: {}", line);

    if let Err(e) = ureq::post(url)
        .set("Content-Type", "text/plain; charset=utf-8")
        .set("Accept", "application/json")
        .send_string(line)
    {
        // If upload fails then print a warning and discard the packet.  We
        // could buffer packets which don't upload.
        match e {
            ureq::Error::Status(_code, response) => {
                eprintln!("Influx POST returned response {:?}", response);
                eprintln!("Influx response body {}", response.into_string().unwrap());
            }
            ureq::Error::Transport(t) => {
                eprintln!("Transport error posting to influx: {:?}", t);
            }
        }
    }
}

fn main() {
    let path = "/dev/ttyACM0";
    println!("Opening serial port");
    let port = open_serial_port(path);
    println!("Making new bufreader");
    let b = BufReader::new(port);
    println!("Waiting for lines....");

    for line in b.lines().into_iter().flatten() {
        // Trim off whitespace
        let line = line.trim();

        println!("Received: {}", line);

        // Ignore any malformed packets
        match ukhasnet_parser::parse(&line.to_owned()) {
            Ok(mut packet) => {
                // Add this gateway to the packet's path
                packet.path.push(ORIGIN.to_owned());

                // Ignore any packets which can't be made into an influx string
                if let Ok(influx_str) = ukhn_to_influx::packet_to_influx(line, &packet) {
                    upload_to_influx(&influx_str);
                }
            },
            Err(e) => eprintln!("Parse failed: '{}' {}", line, e),
        }
    }
}

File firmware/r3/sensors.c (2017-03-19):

#include <stdint.h>
#include <stdbool.h>

#include "ch.h"
#include "hal.h"

#include "sensors.h"
#include "util.h"

const uint8_t ms5637_address = 0b01110110;
uint16_t ms5637_prom[7];
const uint8_t htu21d_address = 0x40;

/* Convert raw temperature from HTU21D to signed integer 0.1C */
int32_t convert_temperature(uint16_t raw)
{
    int64_t temp = raw;
    temp *= 175720;
    temp /= (1<<16);
    temp -= 46850;
    temp /= 100;
    return temp;
}

/* Convert raw humidity from HTU21D to unsigned integer RH percent */
uint8_t convert_humidity(uint16_t raw)
{
    uint32_t hum = raw;
    hum *= 125;
    hum /= (1<<16);
    hum -= 6;
    return hum;
}

/* Get temperature from HTU21D */
uint16_t get_temperature(void)
{
    uint8_t tx_buf[1];
    uint8_t rx_buf[3] = {0, 0, 0};
    msg_t result;

    tx_buf[0] = 0xe3; /* temperature, hold master */

    /* Transmit command to begin temperature measurement */
    result = i2cMasterTransmitTimeout(&I2CD1,
                                      htu21d_address,   // address
                                      tx_buf, 1,        // tx buffer and length
                                      rx_buf, 0,        // rx buffer and length
                                      TIME_INFINITE);   // No timeout
    if(result != MSG_OK)
    {
        volatile uint8_t error = i2cGetErrors(&I2CD1);
        panic("Temperature cmd return != MSG_OK");
    }

    /* Now try to read back -- slave will hold until ready */
    result = i2cMasterReceiveTimeout(&I2CD1,
                                     htu21d_address,    // address
                                     rx_buf, 3,         // rx buffer and length
                                     TIME_INFINITE);
    if(result != MSG_OK)
    {
        volatile uint8_t error = i2cGetErrors(&I2CD1);
        panic("Temperature read return != MSG_OK");
    }

    // Sometimes MSbit of MSB sometimes gets improbably set
    rx_buf[0] &= 0x7f;

//    if(rx_buf[1] & 0x02)
//        panic("Temperature result is of type humidity!");

    /* Retrieve 14-bit measurement, ignoring 2 LSBits */
    return ((uint16_t)rx_buf[0] << 8) | (rx_buf[1] & 0b11111100);
}

/* Get humidity from HTU21D */
uint16_t get_humidity(void)
{
    uint8_t tx_buf[1];
    uint8_t rx_buf[3];
    msg_t result;

    tx_buf[0] = 0xe5; /* humidity, hold master */

    /* Transmit command to begin humidity measurement */
    result = i2cMasterTransmitTimeout(&I2CD1,
                                      htu21d_address,   // address
                                      tx_buf, 1,        // tx buffer and length
                                      rx_buf, 0,        // rx buffer and length
                                      TIME_INFINITE);   // No timeout
    if(result != MSG_OK)
    {
        volatile uint8_t error = i2cGetErrors(&I2CD1);
        panic("Humidity cmd return != MSG_OK");
    }

    /* Now try to read back -- slave will hold until ready */
    result = i2cMasterReceiveTimeout(&I2CD1,
                                     htu21d_address,    // address
                                     rx_buf, 3,         // rx buffer and length
                                     TIME_INFINITE);
    if(result != MSG_OK)
    {
        volatile uint8_t error = i2cGetErrors(&I2CD1);
        panic("Humidity read return != MSG_OK");
    }

//    if(!(rx_buf[0] & 0x02))
//        panic("Humidity result is of type temperature!");

    /* Retrieve 14-bit measurement, ignoring 2 LSBits */
    return ((uint16_t)rx_buf[0] << 8) | (rx_buf[1] & 0b11111100);
}

/* Initialise MS5637 pressure sensor */
void pressure_init(void)
{
    uint8_t tx_buf[1];
    uint8_t rx_buf[2];
    msg_t result;

    tx_buf[0] = 0x1e; /* reset */
    result = i2cMasterTransmitTimeout(&I2CD1, ms5637_address,
                                      tx_buf, 1,
                                      rx_buf, 0,
                                      TIME_INFINITE);
    if(result != MSG_OK)
    {
        volatile uint8_t error = i2cGetErrors(&I2CD1);
        panic("Pressure cmd return != MSG_OK");
    }

    /* Read 6 values from PROM */
    for(uint8_t prom_addr=0; prom_addr<7; prom_addr++)
    {
        tx_buf[0] = 0xa0 | (prom_addr << 1);
        /* Do these two separately as the ms5637 datasheet seems to imply that
           we need an I2C stop between the command and actually reading */
        result = i2cMasterTransmitTimeout(&I2CD1, ms5637_address,
                                          tx_buf, 1,
                                          rx_buf, 0,
                                          TIME_INFINITE);
        result = i2cMasterReceiveTimeout(&I2CD1, ms5637_address,
                                         rx_buf, 2,
                                         TIME_INFINITE);
        ms5637_prom[prom_addr] = (uint16_t)rx_buf[0] << 8 | rx_buf[1];
    }
}

/* Get pressure from MS5637 */
uint32_t get_pressure(void)
{
    uint8_t tx_buf[1];
    uint8_t rx_buf[3];
    uint32_t d1;
    uint32_t d2;

    /* Read D1 */
    tx_buf[0] = 0x40; /* Read D1 with 256 oversampling */
    i2cMasterTransmitTimeout(&I2CD1, ms5637_address,
                             tx_buf, 1, rx_buf, 0, TIME_INFINITE);
    chThdSleepMilliseconds(1);
    tx_buf[0] = 0x00; /* Read ADC on MS5637 */
    i2cMasterTransmitTimeout(&I2CD1, ms5637_address,
                             tx_buf, 1, rx_buf, 0, TIME_INFINITE);
    i2cMasterReceiveTimeout(&I2CD1, ms5637_address,
                            rx_buf, 3, TIME_INFINITE);
    d1 = (uint32_t)rx_buf[0] << 16 | (uint32_t)rx_buf[1] << 8 | rx_buf[2];

    /* Read D2 */
    tx_buf[0] = 0x50; /* Read D2 with 256 oversampling */
    i2cMasterTransmitTimeout(&I2CD1, ms5637_address,
                             tx_buf, 1, rx_buf, 0, TIME_INFINITE);
    chThdSleepMilliseconds(1);
    tx_buf[0] = 0x00; /* Read ADC on MS5637 */
    i2cMasterTransmitTimeout(&I2CD1, ms5637_address,
                             tx_buf, 1, rx_buf, 0, TIME_INFINITE);
    i2cMasterReceiveTimeout(&I2CD1, ms5637_address,
                            rx_buf, 3, TIME_INFINITE);
    d2 = (uint32_t)rx_buf[0] << 16 | (uint32_t)rx_buf[1] << 8 | rx_buf[2];

    /* Difference between actual and reference temperature */
    int32_t dT = d2 - (int32_t)ms5637_prom[5] * 256;
    /* Actual temperature */
    int32_t temp = 2000 + dT * (int32_t)ms5637_prom[6] / 8388608;
    /* Pressure offset at actual temperature */
    int64_t off = (int64_t)ms5637_prom[2]*131072
                + ((int64_t)ms5637_prom[4]*dT) / 64;
    /* Pressure sensitivity at actual temperature */
    int64_t sens = (int64_t)ms5637_prom[1] * 65536
                 + ((int64_t)ms5637_prom[3] * dT) / 128;
    /* Temperature compensated pressure in hundredths of mbar */
    int32_t p = (d1 * sens / 2097152 - off) / 32768;

    if(p<0)
        panic("Pressure result <0");
    return (uint32_t)p;
}

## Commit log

2015-12-15 Schematic: psu, light, pressure, RH
    [teapot.kicad_pcb, teapot.sch]
2015-12-15 schematic part for STM32F070F6P6
    [teapot.sch]
2015-12-15 Added RFM95W, uC support stuff
    [teapot.sch]
2015-12-15 Initial uC pin assignment
    [teapot.sch]
2015-12-20 Changed stm32f070 to stm32l052k8u6
    Also did mcu decouplers properly
    [teapot.sch]
2015-12-20 Added watch crystal
    [teapot.sch]
2015-12-20 Added microusb-b connection
    [teapot.sch]
2015-12-20 Fixed derpy footprints
2015-12-20 Footprints and first test board layouts.
    [teapot.kicad_pcb, teapot.sch]
2015-12-21 Added USB LDO. Resolves #9
    [teapot.kicad_pcb, teapot.sch]
2015-12-21 Added microusb footprint, resolves #6
    [teapot.kicad_pcb, teapot.sch]
2015-12-21 Added ESD-protection TVSs. Resolves #7
    [teapot.sch]
2015-12-21 Finished speccings parts and footprints.
    Resolves #3
    [teapot.kicad_pcb, teapot.sch]
2015-12-21 Fixed a couple of footprint derps
    [teapot.kicad_pcb, teapot.sch]
2015-12-22 Power consumption calculations
    Resolves #5, resolves #2
    [power.ods, teapot.kicad_pcb, teapot.sch]
2015-12-22 Added battery level monitor
    [teapot.kicad_pcb, teapot.sch]
2015-12-24 added mounting holes. resolves #8
    [teapot.kicad_pcb]
2015-12-27 Initial placement and first successful route.
    [teapot.kicad_pcb, teapot.sch]
2015-12-31 gerber export of first test route
    [teapot-B.Cu.gbl, teapot-B.Mask.gbs, teapot-B.SilkS.gbo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]
2015-12-31 Made schematic look beautiful. Fixes #4
    [teapot.sch]
2015-12-31 Setup boardhouse capabilities, track/via spec
    [teapot.kicad_pcb]
2015-12-31 Fixed some ERC issues
    [teapot.sch]
2015-12-31 Changed to agg's microusb-ab connector
    [teapot.kicad_pcb, teapot.sch]
2015-12-31 New test placement with smaller pcb outline
    [teapot.kicad_pcb, teapot.sch]
2015-12-31 Added test points and ANT PTH footprint
    [teapot.kicad_pcb, teapot.sch]
2016-01-01 Changed all 0805 (except LEDs) to 0603
    [teapot.kicad_pcb, teapot.sch]
2016-01-01 0603 test placement
    [teapot.kicad_pcb]
2016-01-01 layout switcher psu
    [teapot.kicad_pcb]
2016-01-01 Routed 3v3 and some GND.
    [teapot.kicad_pcb]
2016-01-02 Added tag-connect for programming
    [teapot.sch]
2016-01-02 Second test route on new outline/placement
    [teapot-B.Cu.gbl, teapot-B.Mask.gbs, teapot-B.SilkS.gbo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]
2016-01-03 Rerouted most of test route 2
    [teapot.kicad_pcb, teapot.sch]
2016-01-03 Re-orientated RFM69W
    [teapot.kicad_pcb]
2016-01-03 Updated microusb part
    [teapot.kicad_pcb]
2016-01-05 Moved mounting holes. Fixes #10
    [teapot-B.Cu.gbl, teapot-B.Mask.gbs, teapot-B.SilkS.gbo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]
2016-01-05 Moved antenna a bit, worked on silk
    [teapot.kicad_pcb]
2016-01-06 Fixed DRC clearance bugs
    [teapot.kicad_pcb]
2016-01-06 Added DIO0,4. Fixes #12
    [teapot.kicad_pcb, teapot.sch]
2016-01-06 Final tidying, fixes #11
    [teapot.kicad_pcb]
2016-01-06 Changed mounting to holes, updated gerbers
    [teapot-B_Cu.gbl, teapot-B_Mask.gbs, teapot-B_SilkS.gbo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]
2016-01-06 Moved LEDs, reduced mask clearance
    [teapot-B_Cu.gbl, teapot-B_Mask.gbs, teapot-B_SilkS.gbo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]
2016-01-06 Fixed input voltage silk
    [teapot.kicad_pcb]
2016-01-07 Proper mounting holes, fixes #14
    [teapot.kicad_pcb]
2016-01-07 Silk issues, sensor overlap. Fixes #17, #16, #15
    [teapot-B_Cu.gbl, teapot-B_Mask.gbs, teapot-B_SilkS.gbo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]
2016-01-07 Final fiddling
    [teapot-B_Cu.gbl, teapot-B_Mask.gbs, teapot-B_SilkS.gbo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]
2016-01-12 Changed to stm32l052k6t6 (lqfp32)
    [teapot-B.Cu.gbl, teapot-B.Mask.gbs, teapot-B.SilkS.gbo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]
2016-01-12 Added LQFP32, most of first route of new layout
    [teapot.kicad_pcb, teapot.sch]
2016-01-12 First layout and route of new lqfp micro
    [teapot-B.Cu.gbl, teapot-B.Mask.gbs, teapot-B.SilkS.gbo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]
2016-01-25 Added DIO0/4 to schematic
    [teapot.sch]
2016-01-25 Routed DIO0+DIO4
    [teapot.kicad_pcb, teapot.sch]
2016-01-25 Various fiddling, ready to ship r1 gerbers
    [teapot-B.Cu.gbl, teapot-B.Mask.gbs, teapot-B.SilkS.gbo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]
2016-02-11 Fixed up capabilities for ragworm, successful manufacture
    [teapot-B.Cu.gbl, teapot-B.Mask.gbs, teapot-B.SilkS.gbo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]
2016-02-18 r2 BOM
    [bom.ods]
2016-02-18 First test print of case
    [assembled.SLDASM, case.SLDPRT, case.STL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]
2016-02-19 Enlarged LED holes to 1.5mm. Resolves #19
    Up from 1mm
    [assembled.SLDASM, case.SLDPRT, case.STL]
2016-02-19 Reduced wall thicknesses to 1mm. Fixes #18
    [assembled.SLDASM, case.SLDPRT, lid.SLDPRT]
2016-02-19 Lid CSK + reinforcement, fixes #21
    [assembled.SLDASM, lid.SLDPRT]
2016-02-19 Fixed weird upper ledge, fixes #20
    [case.SLDPRT]
2016-02-19 Updated STLs
    [assembled.SLDASM, case.STL, lid.STL]
2016-02-19 Reduced top and bottom thickness. Fixes #22
    [assembled.SLDASM, case.SLDPRT, lid.SLDPRT]
2016-02-19 Regenerated STLs
    [case.STL, lid.STL]
2016-02-23 Initial firmware, i.e. flash LEDs.
2016-02-24 power spreadsheet time averages
    [power.ods]
2016-02-24 Most pin assignments and modes
2016-03-18 Updated agg-kicad for stickerbom
2016-03-19 Changed libopencm3 to track cillian64 fork
2016-03-19 Added reset to rfm69 bringup
    [teapot_pins.c]
2016-03-19 Actually release RFM69 from reset
    [rfm69.c]
2016-03-19 fix bug in setfreq
    [rfm69.c]
2016-03-20 Fix shift direction bug
    [rfm69.c]
2016-03-20 ADC and light sensor
2016-04-10 Fixed ADC (can only do 12-bit convert)
    [analog.c, teapot.c]
2016-04-11 Wrote i2c driver. Hopefully.
2016-04-12 Removed 10-bit addressing from i2c driver
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2016-04-13 Removed 10-bit flag from temp/hum i2c reads
2016-04-14 Open drain i2c outputs
2016-04-15 Added optional i2c restarting
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2016-06-17 Budged agg-kicad to cillian64 fork
2016-06-17 Sch: removed usb, pwr led, swd
    [teapot.sch]
2016-06-17 Migated PSU and boilerplate to new QFN-64 micro
    [teapot.sch]
2016-06-17 Ripped up old PCB.
    [teapot.kicad_pcb, teapot.sch]
2016-06-17 Fixed HTU21D and MS5637 footprints.
    Fixes #37
    Fixes #35
2016-06-17 new board outline with 4xM2.5 mounting holes
    [teapot.kicad_pcb]
2016-06-17 Added AMG88 part/fp
    [teapot.sch]
2016-06-17 Initial placement
    [teapot.kicad_pcb, teapot.sch]
2016-06-17 Second placement
    [teapot.kicad_pcb, teapot.sch]
2016-06-17 Pin assignment and final placement??
    [teapot.kicad_pcb, teapot.sch]
2016-06-17 First route
    [teapot.kicad_pcb, teapot.sch]
2016-06-17 Reinstated SMA, silk fiddling
    [teapot.kicad_pcb, teapot.sch]
2016-06-17 Neatened schematic
    [teapot.sch]
2016-06-17 Moved ANT TP outside of AA cell holder
    [teapot.kicad_pcb]
2016-06-19 Fixed HTU21D and MS5637 FPs
    Had updated FP files but not updated in board
    [teapot-B.Cu.gbl, teapot-B.Mask.gbs, teapot-B.SilkS.gbo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]
2016-06-19 Fixed clearance violation, removed bogus silk
    [teapot-B.Cu.gbl, teapot-B.Mask.gbs, teapot-B.SilkS.gbo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]
2016-06-19 added p1 indicator to AMG88
    [teapot-B.Cu.gbl, teapot-B.Mask.gbs, teapot-B.SilkS.gbo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]
2016-06-19 Thickened up radio VCC tracks
    [teapot.kicad_pcb]
2016-06-19 Updated gerbs
    [teapot-B.Cu.gbl, teapot-B.Mask.gbs, teapot-B.SilkS.gbo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]
2016-06-26 Added BOM, spreadsheet and stickerbom
    [bom.ods, teapot.sch]
2016-06-27 Updated BOM for old r2 parts found
    [bom.ods]
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2016-06-28 Fixed bugs in ChibiOS base setup
    [board.h, halconf.h, main.c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]
2016-06-29 Analog test driver: doesn't work
    [analog.c, main.c]
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2016-07-07 Fixed typos, added flash on rx
    [main.c]
2016-07-07 Disable semihosting, disable i2c DMA (clashed with spi)
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2017-03-13 new lasercut r3 case
    [assembled.SLDASM, case.SLDPRT, case.STL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]
2017-03-15 re-imported board-r2
    [bom.ods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]
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2017-03-18 Fixed python shebang on osx
    [gateway.py, grid_receiver.py]
2017-03-19 Panic with reason, fix temp sensor
    [main.c, rfm69.c, sensors.c]
2017-03-19 Add temperature MSB MSbit bodge
    [sensors.c]
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2017-03-19 fix humidity measurement bug
    [sensors.c]
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2022-08-25 Prototype influxdb backend
    Post lines straight to local InfluxDB instead of to the ukhas.net
    gateway
2022-08-26 Convert r3 PCB to KiCAD v6 format
    [teapot.kicad_pcb, teapot.kicad_sch]
